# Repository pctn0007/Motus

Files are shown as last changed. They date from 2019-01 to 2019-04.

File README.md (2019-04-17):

<p align="center">
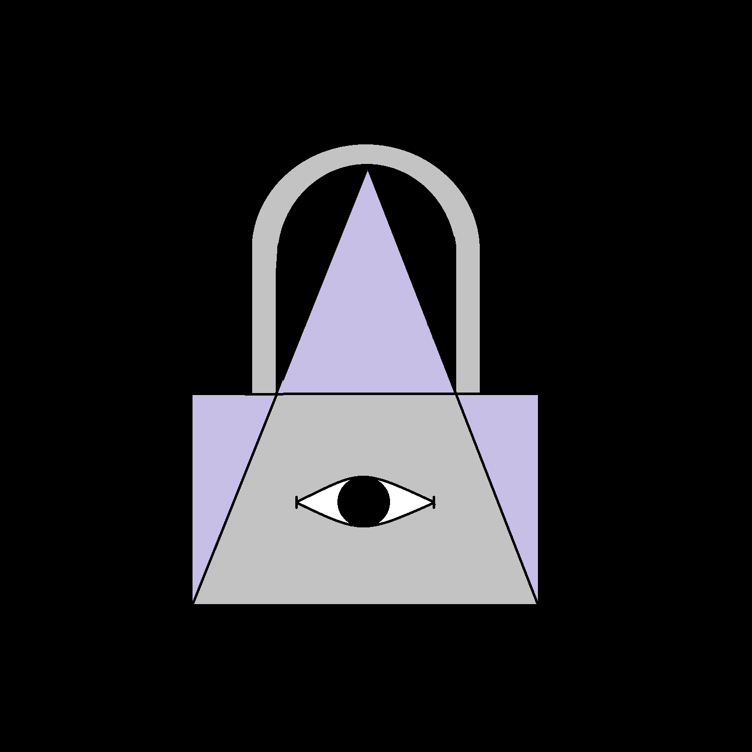
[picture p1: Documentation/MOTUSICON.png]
ICON
  
  <br>
  <b font size="20">M O T U S</b><br>
  <b font size="30">"The Portable Security System"</b>
</p>
<br>
Motus is a Student Project that is designed to be an Active Remote Security System that can be placed within a car, a boat, in your purse, even your purse inside your prius! Or etc. This device is designed to alert the owner of their certain vehicle or valuable items / objects of any individual altering its movement, position or if someone is inside it or manipulating it in general. Motus monitors multiple factors, such as movement, and motion. Motus will snap a picture and alert you of any intrudors or thieves messing with your protected belonging.
<br><br>This project is being worked on by the following people:
<br>- Anthony Pacitto (pctn0007 [MASTER])
<br>- Dariusz Kulpinski (BlueDaroosh)
<br>- Winston Vuong (LosesonWinson)
<br>- All three students are Computer Engineering Students currently studying at Humber College in Toronto, CAN.

<br> [Click here to access the Build Instructions](https://github.com/pctn0007/Motus/blob/master/BUILDINSTRUCTIONS.md)

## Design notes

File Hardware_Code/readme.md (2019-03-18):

# MOTUS Logic:
[MOTUSLOGIC.py](https://github.com/pctn0007/Motus/blob/master/Hardware_Code/MOTUSLOGIC.py)
# Camera / Image Shell Scripts:
[CAMERA.sh](https://github.com/pctn0007/Motus/blob/master/Hardware_Code/CAMERA.sh)
[IMAGE.sh](https://github.com/pctn0007/Motus/blob/master/Hardware_Code/IMAGE.sh)

test_scripts directory contains old testing / reference code.

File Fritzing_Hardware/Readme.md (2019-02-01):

I will stick images of the PCB, Wiring Diagram and Breadboard Eventually in here.

~ Dariusz

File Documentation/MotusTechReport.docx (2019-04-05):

## Motus Technical Report

Prepared by Anthony Pacitto,

Dariusz Kulpinski,

Winson Vuong

Date: 3/22/2019

# Abstract

The Motus Security System(MSS) is a portable security system that would detect motion in front of the device or movement of the device, and after detecting said motion it would capture an image using the Raspberry Pi Camera apparatus attached directly on the device. The MSS after capturing the image would then send the image to a database, and would then be seen on an Android application. This Technical document for the MSS is used to record our progress, and our findings from our progression throughout the project. The document would record what we as a group did to create the hardware for the MSS. Also, we would describe how exactly managed to create our software for both the Raspberry Pi and also our Android application. Problems we faced will also be included and how we as a group managed to move passed them as a group. The report will also contain our weekly updates to our project that would give insight to how the project was managed as a group, and how we worked together to create this project. The final findings of the project will also be included in this document, and will be recorded as detailed as possible for the sake of proper reporting.

# Declaration of Joint Authorship

We, Anthony Pacitto, Dariusz Kulpinski, and Winson Vuong, confirm that this work submitted is the joint work of our group, and no plagiarism has occurred . Any references used in the report will be noted and documented throughout the report. The list of the references used for the report will be included inside the document. For the project Anthony handled the database portion of the project and the app. Dariusz worked on all the physical and hardware portion of the project. And Winson worked on supporting the both of them as an assistant for the project and is working on the app.

# Approved Proposal

# Concluding remarks

# Illustration List

# 1 Introduction

Motus Security System (MSS) is branded as a portable motion sensor that can be used to detect both physical motion and local vibrations (i.e. tampering or movement of the device) in a 100 degree targeted zone. As mentioned, the software being specified within this document is known as: Motus Mobile and its purpose are to provide the MSS user full control and monitoring of basic input data via the MSS hardware device. The Motus Mobile will also contain a login system for multiple users to use the MSS. The software application provides access to the devices remote database system (i.e. Firebase) which evidently stores all sensor data for interpretation, and also the images captured by the Raspberry Pi Camera. The benefit and overall goal of the application will allow for a user to remotely control their device from any location around the globe in order to ensure greater security, all within an efficient manner. It will monitor information such as, device tampering and movement notifications, surrounding motion detection and image capturing based on where a movement was detected. Additional application settings and preferences will be available which can be modified based on the user’s discretion.

# 2 Project Description

2.1 Problem

# 2.2 Rationale Behind Project

# 2.3 Project Scope

# 2.4 Software Requirement Specifications

# 2.4.1 Database

# 2.4.2 Mobile Application

# 2.4.3 Web Interface

# 2.4.4 Networked Platform Communication Software

# 2.4.5 Microcontroller Firmware

# 2.5 Project Overview

# 2.5.1 Bill of Materials

# 2.5.2 Time Commitment

# 2.5.3 Mechanical Assembly

# 2.5.4 PCB and Soldering

# 2.5.5 Power Up

# 2.5.6 Unit Testing

# 2.5.7 Production Testing

# 2.6 Problems Encountered

# 2.7 Approaches

# 2.8 Walkthrough of System

# 2.8.1 Microcontroller

# 2.8.2 Microprocessor

# 2.8.3 Server

# 2.8.4 Phone Application

# 3. Progress Reports

# 3.1 Report 1

# 3.2 Report 2

# 3.3 Report 3

# 3.4 Report 4

# 3.5 Report 5

# 3.6 Report 6

# 4. Conclusions

# 5. Recommendations

# 6. Technical References

# 7. Appendicies

# 7.1 Microcontroller Firmware

# 7.2 Microprocessor Communication Script

# 7.3 Microprocessor Database Communication Program

# 7.4 Database Input Script

# 7.5 Database Retrieval Script for Phone Application

# 7.6 Android Code

# 7.7 Android Phone Application

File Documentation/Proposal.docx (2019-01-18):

Proposal

Team

This letter is to propose the build and production of a portable in-home motion sensor to serve as the backbone for both residential and commercial security systems. The name of the project is known as: Motus (i.e. latin translation of “movement”) and its team consists of the following members: Anthony Pacitto, Dariusz Kulpinski, and Winson Voung.

Introduction

As stated above, Motus will be branded as a portable motion sensor that can be used to detect both physical motion and local vibrations (i.e. tampering or movement of the device) in a targeted zone. In addition, the hardware will support a fully featured mobile application that will provide full control over the device’s settings and detectable readings. With respect to the overall size of the product, the device will contain dimensions that will be small enough for a user to easily mount to any given door, wall, and/or window ledge that they see fit. Currently, there are small in-home sensors; however, not all are portable from one environment to another while maintain mobile compatibility – making Motus somewhat unique versus other makes and models.

Courses and Topics

After much thought, it is important to note that the listed courses and topics that will be relatable to this project are as follows:

- CENG150 - Electronic Circuits:
  - Interpretation of sensor datasheets and electrical circuit design
- CENG153 - Programming in C:
  - Fundamentals of standard input/output and device coding
- CENG252 - Embedded Systems:
  - Implementation of Raspberry Pi with other motion sensors
- CENG322 – Software Project:
  - Java programming for android platform with working database source.

As a team, we plan to use a three-way communication processes between: i) the mobile application; ii) remote cloud/database (i.e. Firebase); and, iii) hardware device. The mobile device will be responsible as rendering the detected any data output via the hardware, in addition to providing a system control interface for the user. The remote cloud will be used to store motion and user data based on the devices input (i.e. HC-SR501 PIR - infrared motion sensor; ADXL 345 – accelerometer; Raspberry Pi 3). It is important to note that this will be the primary way we retrieve digital data and information.

Application and Scheduling

We predict that over the course of the next 13 weeks, we will breakdown the project into 3 phases: 1) design (i.e. mobile application GUI; device designs and layouts), 2) build and develop (i.e. programming of the application, hardware construction/ soldering), and 3) implementation and Testing/Debugging (i.e. testing application on various platforms; testing synchronization between database, app and device; test device in various motion-based environments). Each phase will be completed over an estimated 3.25 weeks accordingly and the workload per team member will be distributed evenly between both hardware and software portions; however, many tasks will be appointed based on comfort level and experience (e.g. greater focus on hardware vs. software).

As for the application, we plan to incorporate, but will not limit to the following activities (screens):

- Splash screen
- Log in and registration
- Motion detection records
- Settings
- Placeholder menus
- Help

The application will contain a hierarchical level system for its activities in order to assure a smooth navigational experience throughout the application. As stated before, we intend to complete this bug-free application over a 13 week period on time. If we do run into any time restraints or complications within the middle, we will negotiate tasks and workload and call for group meetings in order to get back on track; thus, altering our critical path accordingly.

Conclusion

In conclusion, our team feels confident that we can provide a new portable security system that will make it easier for people to portably move there security zone. Not only do we intend to have a working hardware device, but also a fully incorporated Firebase system which communicate over android application platform.

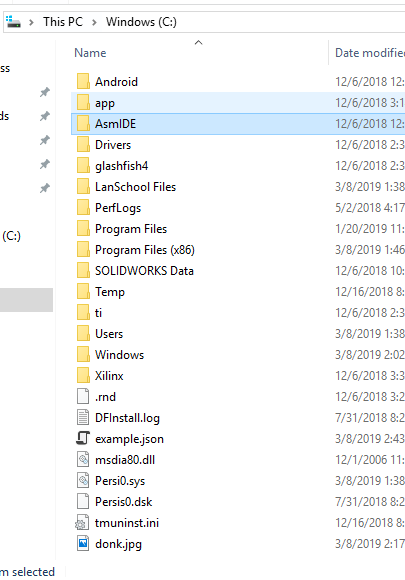
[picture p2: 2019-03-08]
Research/Capture.PNG

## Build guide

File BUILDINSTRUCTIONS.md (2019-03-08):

# MOTUS - The Handheld Security System
## Anthony Pacitto, Dariusz Kulpinski, Winston Vuong 
## CENG 355-0NC
![DeviceImage]()

# BUILD INSTRUCTIONS / How to make a MOTUS device yourself

These are the build instructions on how to make the device. Some items may be more complex to complete, as they need special equipement to complete (ex. PCB builders, CO2 Laser Cutter / Etcher, etc.)

To start off, we should determine what this should look like in the end. More suitably for this project, what should our output look like? Well, fist of all it must detect any security breaches. Such that it can detect if theres motion, or movement of the device itself. In terms of build time for this project, it's a good idea to prepare everything before hand, such as part ordering and source downloads of items and code, pre-manufacturing items and whatsoever. If you are ready to commence the build, you can find a good 3-4 weeks to assemble the entire thing together, as there are many components to review.

## What do we need to start off with?

Several components are required in order to make this project work. All required components for this project is listed below:

- Safety Glasses (Eye protection and other protection you prefer)
- Raspberry Pi 3 B+ Model (Must be I2C ready.)
- SD Card with Raspbian OS (Available Online or install image on own SD card.)
- ADXL345 3 Axis Accelerometer (This is the movement detector. Must be I2C ready.)
- HC-SR501 PIR Sensor Module (This is the motion detector. Must work with GPIo.)
- Standard LED (Used as an indicator for the device)
- 330 Ohm Resistor (To limit voltage on the LED)
- Rapsberry Pi External Camera (For the Photo Component of the device.)
- Breadboarding Platform (Any Size Works)
- USB mouse, USB Keyboard, HDMI cable and HDMI monitor to use the Pi With OR ethernet cable to use the remote desktop function.
- GPIo Cables (male to female connections between board and sensor)
- GPIo Pin Stacking Header (Something that allows you to connect a PCB itself to the Pi)
- 3 Pin Stacking Headers (Used to space the motion sensor from the board)
- Jumper Wires (Used for the PCB component or the breadboarding if preffered)
- Wire stripping / Cutting tools
- Soldering Equipment (Soldering Iron, Lead Free Solder, Proper Ventilation, Wet Sponge, Solder Sucker, etc)
- Printed Circuit Board (PCB. This will be discussed later.)
- PCB design software (Example. Fritzing. This will be discussed later.)
- Device Enclosure (Such as PVC boards. This will be discussed later.)
- Enclosure Design Software (Example, CorelDraw. This will be discussed later.)
- Some means of way to produce the PCB and the enclosure (This will be discussed later.)
- And of course, some money.

The estimated cost of building this device is around $245.95 CAD.

## Phase 1: Testing The Design.

To start off, we need to make sure that we know how to connect our device and how its going to work in the end.

Four connections are required to connect our accelerometer to the raspberry pi. First we need to supply 3.3V, connect the ground, and connect our I2C data bus and clock bus to the approprate SDA and SCL pins on the pi.
Three connections are required to connect the motion sensor to the pi. We need a 5V connection, a ground connection, and a connection to a GPIO pin. For this project, the GPIo pin we will connnect it to is GPIo7.
Two connections are required to connect the LED. A connection to the 5V pin, and to the ground. The Resistor can be connected inline with the LED anywhere.
To connect the camera, simply slide the ribbon cable into the appropriate cable slot on the pi's board.
Below is the breadboard. This is how it is supposed to be connected in the end:
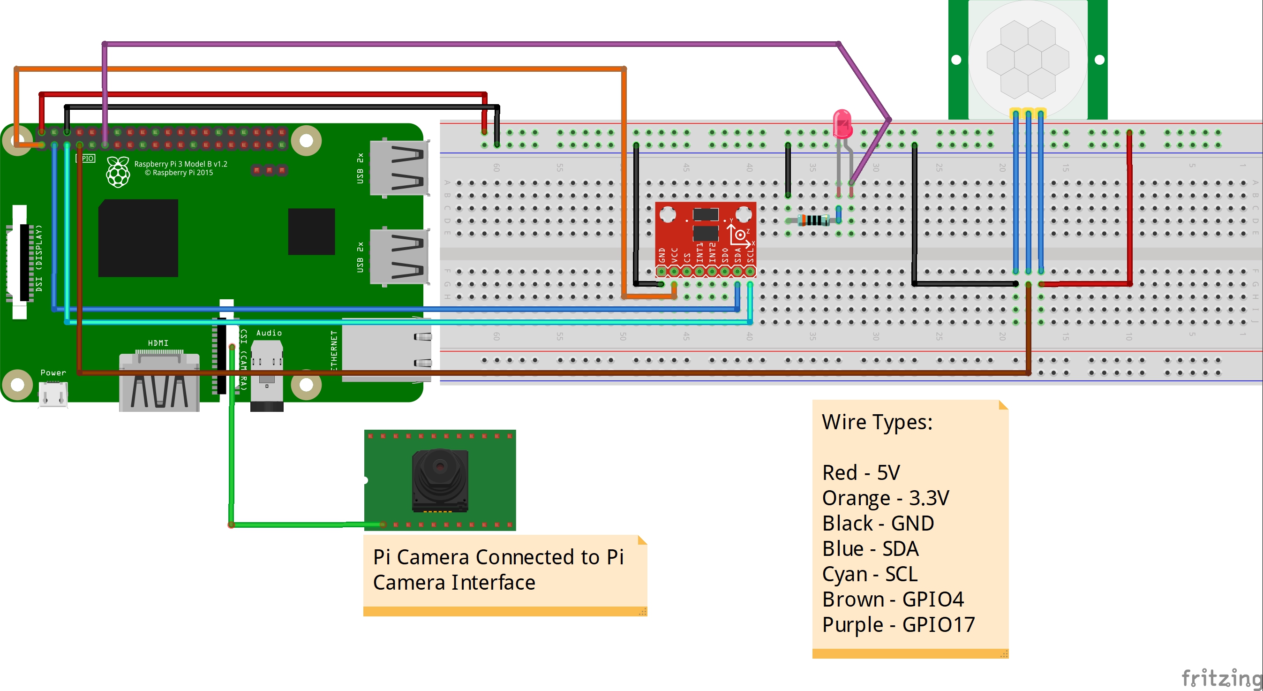
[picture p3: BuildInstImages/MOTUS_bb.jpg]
Breadboard image

#### Pin locations may vary depending on the manufacturer of the sensor itself.
Basically in the end, your wiring must match the schematic as follows:
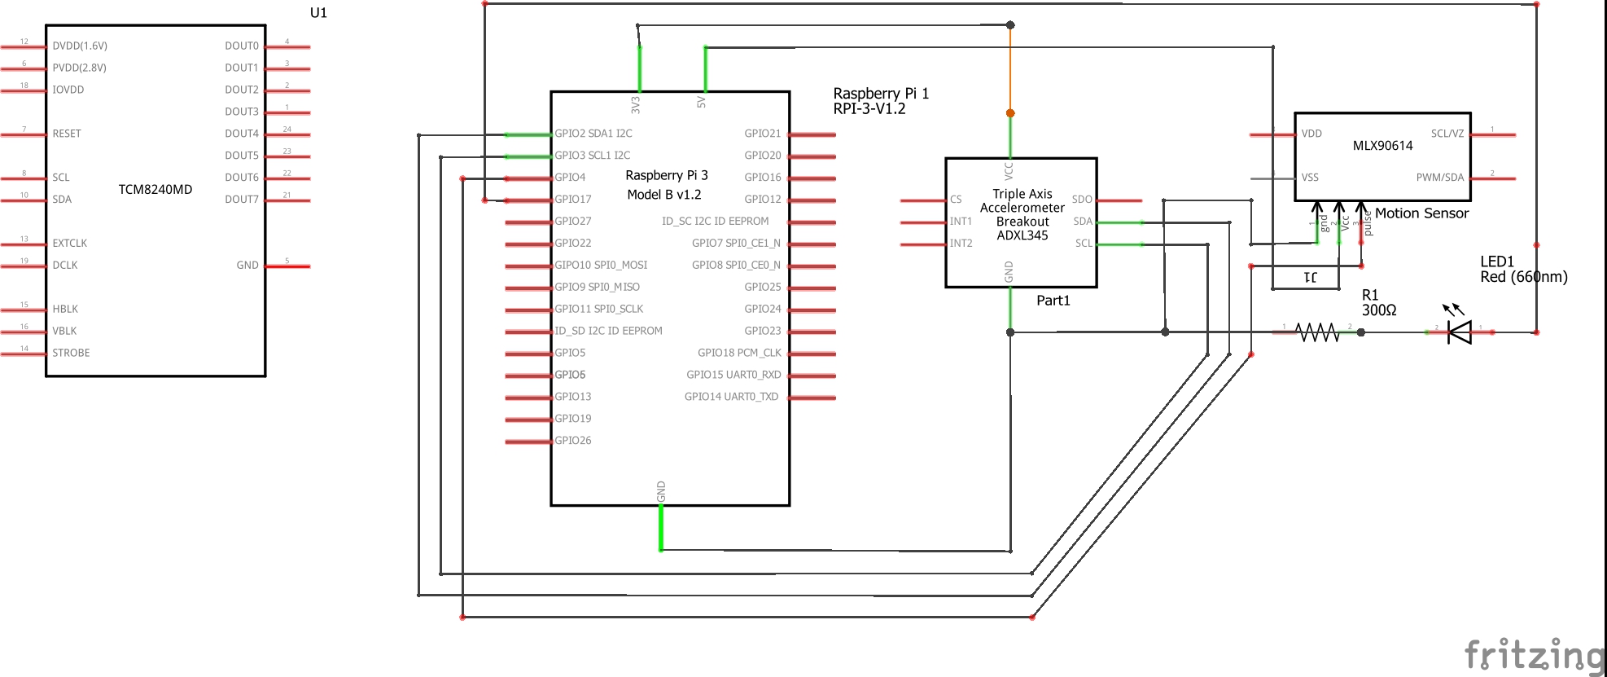
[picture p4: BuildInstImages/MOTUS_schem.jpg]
Wiring Schematic

Once this breadboarding is complete, You have the option to jump towards the Third Phase of the build, which powers on the system, or continue on to the Second Phase to design the circuit board for actual system itself.

## Phase 2: Building a Circuit Board

With our breadboard schematic done, we can now design a circuit board that will eliminate all our wiring in the device. A highly reccomended software for this part is Fritzing. Fritzing is a software that allows you to design a breadboard, wiring diagram, and the circuit board itself with ease.
<br />[Click here to visit Fritzing.org](http://fritzing.org/home/)
<br />Once fritzing is installed, build a breadboard design very similar to the design above. Once designed, a schematic of your board and a PCB template will automatically be generated. All you have to do is simply complete the connections.
<br />For the PCB, make sure that each of the connections are designed to fit the devices, and ensure that they can be soldered on depending on which side the contacts are.
<br />Below is a sample of how the PCB should look like in the end:
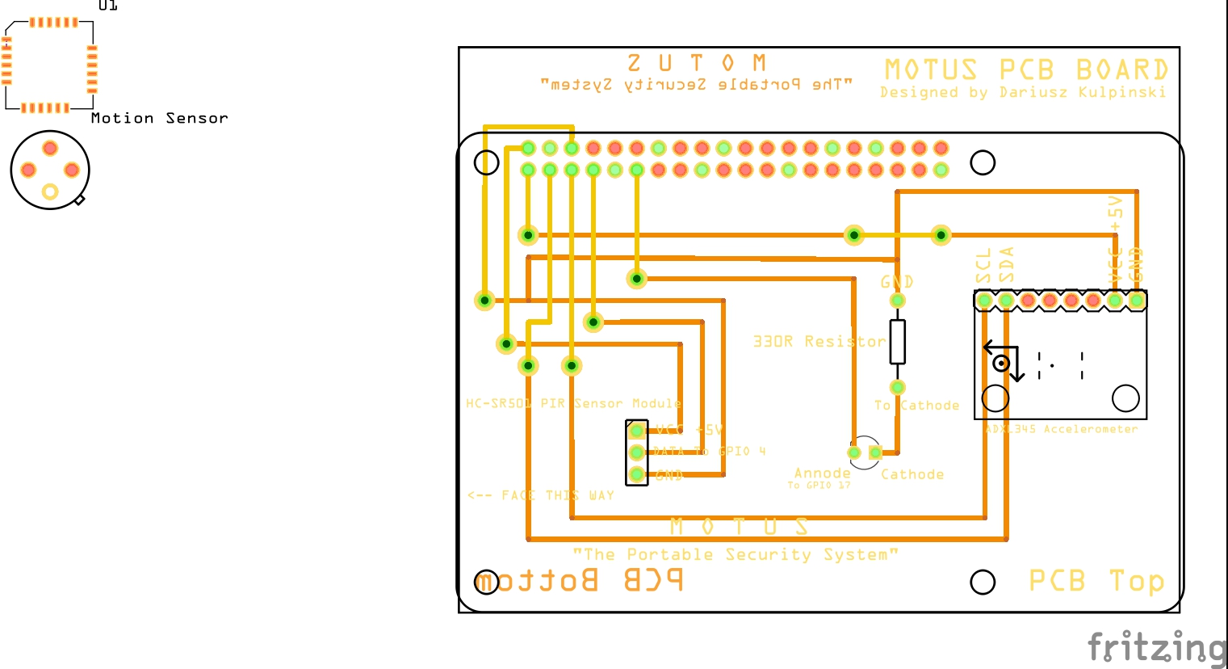
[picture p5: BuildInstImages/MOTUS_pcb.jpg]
PCB Design

<br />[Click here to learn more on how to design a PCB in Fritzing](http://fritzing.org/learning/tutorials/designing-pcb/)
<br />Ensure that the connection to the Pi Header can be soldered on the TOP of the board, and make sure that soldering on the sensor can be done on the BOTTOM of the board. Remember, Yellow lines indicate the TOP, while orange lines indicate the BOTTOM. To connect the bottom and the top together, use VIA'S to link them together. You also have access to the original fritzing file if you want to modify that for yourself. [You can click here to download the fritzing file.](https://github.com/pctn0007/Motus/blob/master/Fritzing_Hardware/MOTUS.fzz)
<br />If you are satisfied with the board design, export the PCB as an Extended Gerber File for manufacturing. If you have access to a PCB builder, you can use that. Otherwise, you need to send these Gerber files to a service that Prints out circuit boards, which may add to your budget.

Once you obtain your circuit board, you can proceed to soldering on the pins. Please ensure that you have proper ventilation for this part, and safety glasses are absolutely mandatory for this part.
[If you need help on soldering, a tutorial can be found here.](https://www.build-electronic-circuits.com/how-to-solder/)
<br />To solder the board, ensure that the sensors pins are soldered on the BOTTOM of the board. Ensure that the PI connectors are soldered on the TOP of the board. To Solder the Vias, take some jumper wire, strip it of its protection and stick it throuhg the via. Solder the jumper on both ends, and cut off the excess. That solders on the via and you linked top to bottom.
<br /> This is an example of how the soldering should be completed:
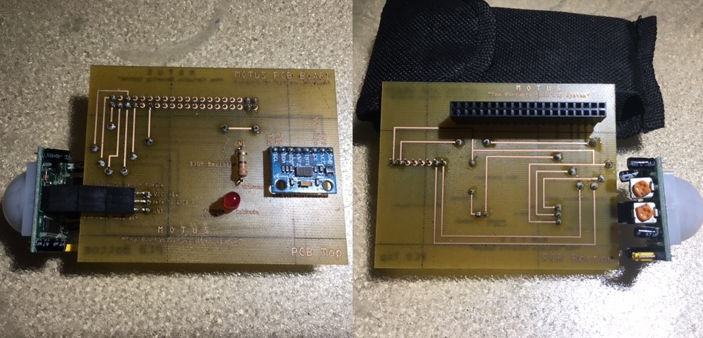
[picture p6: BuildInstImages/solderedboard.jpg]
Soldering Example

Once the board is fully soldered, it's time to move to Phase 3.

## Phase 3: Powering the Accelerometer

In this phase, we will test our design to see if it outputs values and reads from the sensors. This part will be majorly focused on the use of the PI, so this is where the monitor, mouse keyboard and HDMI cable Or Remote Desktop Connection come into play.
If you want to learn more about remote desktop connection and the pi, [you can click here.](http://www.circuitbasics.com/access-raspberry-pi-desktop-remote-connection/)
When you start up your Pi, make sure you complete setup if that has not happened already. The most important part to begin with is to ensure that we can read from our sensor's i2c address. First the Pi must be configured to activate I2C. To do this, go into your Raspberyy Pi Preferences:
Pi Preferences

Under your IO, ensure that the I2C interface is switched to on. That completes this step.
The next step is the i2c tools. To install this, open the terminal and type in:
#### sudo apt-get install -y i2c-tools
<br /> Input your credentials and allow the installation to complete. Once that's done, we check if our sensors i2c address is found on the GPIo. Run the following command in the terminal:
#### sudo i2cdetect -y 1
<br /> Running this, you should get the following result:
GPIo I2C pickup
<br />If you see the address of 0x53, you are all set and the accelerometer is ready. Otherwise you need to go back and see what mistakes you have done.

Let's understand how the code is supposed to work in the end. First of all, when working with I2C, we need to program the system to ensure that it will register and read I2C devices that are connected to the I2C bus. Next thing is how this data should be processed. It depends on how you want to display and store the information. Let's say for example we want to take data from a sensor, store it in a database, and have a mobile device read from that database to display the current values for the accelerometer. Below is some PSEUDO CODE that would demonstrate what we would like to do:
`<https://github.com/BlueDaroosh/handheldSpedometer/blob/master/PseudoCodeAssignment/WriteFromServer.txt>`
`<https://github.com/BlueDaroosh/handheldSpedometer/blob/master/PseudoCodeAssignment/ReadToClient.txt>`

The next part is programming the device itself to take inputs from the sensors. This is written under python, but should be simple to implement. Run Thonny on the pi. Once thonny runs, save a .py file anywhere. Below is a link to the source code.
<br />[Click here to access the source code.](https://github.com/pctn0007/Motus/blob/master/Hardware_Code/MOTUSLOGIC.py)
<br />Also, there is a shell script that is required in order to operate the camera function of the script. The shell script is a call to the raspistill command, and [can be accessed here.](https://github.com/pctn0007/Motus/blob/master/Hardware_Code/MOTUSCAMERA.sh)
<br />Please ensure that the database credentials are modified in the python script so that it connects to the database you configure in Phase 4 of the instructions.
<br />Once you format everything properly, and make sure the syntax is correct, you can run the script. By running the script, the device will search for motion or check for movement. If either are true, the device will emit a warning signal light, and activate the camera. The photo should be accessible under the home directory.
<br /> Feel free to look at the script, and modify it however you please.

## Phase 4: The Database and App
The recommended database to use for this build is known as Google's Firebase realtime database and storage system. First, you must create a google account in order to register your application (via Android Studio) to your remote database. Next, we need to create a new project in Firebase by clicking Add Project under your Firebase Console. It is important to follow each setup step accordingly by importing the correct libraries into your application and project gradle files. It is also important to make sure you add the google-support.json file into your Android Studio application folder/directory. Once you have successfuly added your Android application to your database for connection, we must create a link between the application and the database for development. The video link below will provide a step-by-step tutorial on how to go about creating, adding and connecting your new Android project to your database:

https://www.youtube.com/watch?v=YVu_xSzn2u0

It is important to note that once all setup is complete, you must alter your user permissions accordingly in order to enable read and write privledges so that individuals working on the application have the ability to read/write data to the database.

## Phase 5: The Enclosure

To do the enclosure is totally up to you, but it is highly reccomended so that your components are secured and protected. The example case for this project was made using CorelDraw. Other design softwares can be used as well to create the enclosure.
[This is a link to the example closure, which can be modified to your circuit design.]()
NOTE: This is a coreldraw file, therefore you require coreldraw to edit this file. Unless you do not have a free trial, this may be an additional $600 CAD to the budget. Ridiculous price.
<br />Once you design your enclosure for the circuit, you can take the file and use a locally available CO2 laser etcher or other tool that corresponds to your design. Otherwise you may also require to use a service which will build the enclosure for you, but at an added cost for the budget. Once you get your enclosure parts, build the entire thing together, and that is your final result. Below are images of an example of the final result:
![Enclosure Top]()
![Enclosure Back]()
This marks the end of the project. This entire system is now yours to modify and cherish.

## Final Comments
Motus is a bit of a rough idea, however the entire system can be beneficial to the whole valuable protection scheme. Below are references on how the MOTUS platform was designed and built. MOTUS is under a GNU General Public License, so that it is available for you to use, change, modify or redistribute your modification.

#### Credits and Works Cited. Without these, the project would have not been possible:
Dcube Tech Ventures. (N.D.) 3-AXIS ACCELEROMETER, ADXL345 WITH RASPBERRY PI USING PYTHON. 
Obtained From: https://www.instructables.com/id/3-Axis-Accelerometer-ADXL345-With-Raspberry-Pi-Usi/
<br />AviV1. (N.D.) HOW TO USE THE ADXL345 ON RASPBERRY PI.
Obtained From: https://www.instructables.com/id/how-to-use-the-ADXL345-on-Raspberry-pi/
<br />GPIo: https://www.raspberrypi.org/documentation/usage/gpio/
<br />I2C Wiring: https://www.anstack.com/blog/2016/07/05/accelerometer-intro.html
<br /> Humber College - CENG 317 Hardware Production Tech Course
<br /> Humber College - CENG 355 Capstone Project Course
<br /> Humber School of Applied Technology - Computer Engineering Technology

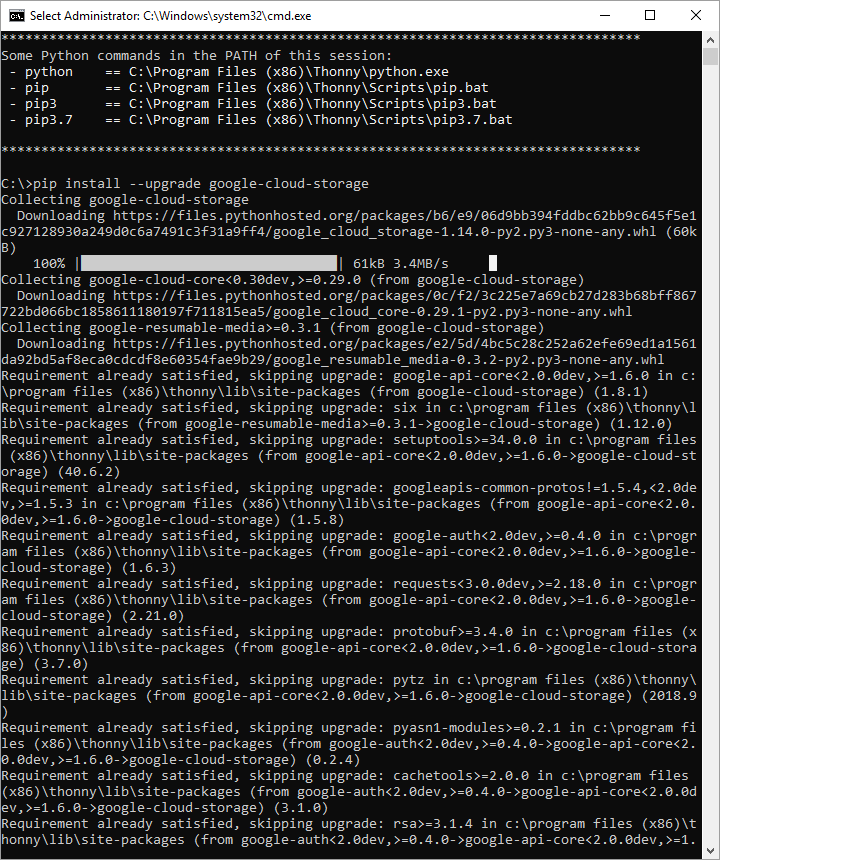
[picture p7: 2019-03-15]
Research/install_google-cloud-storage.png

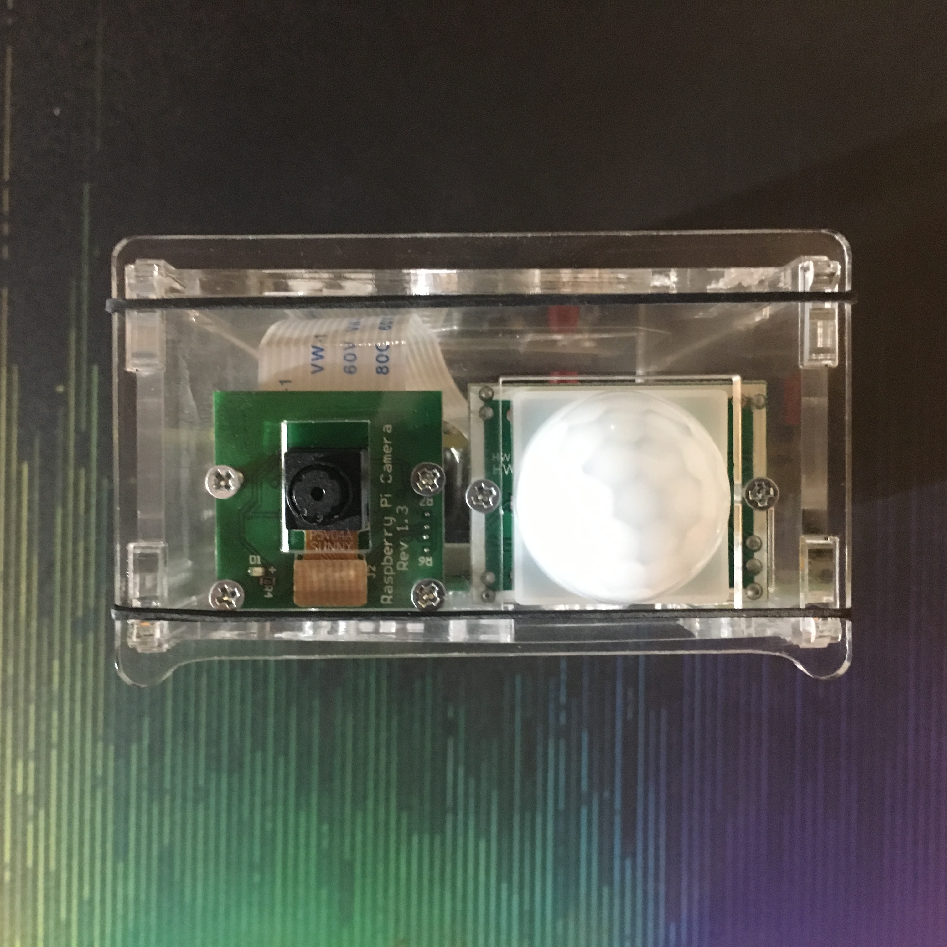
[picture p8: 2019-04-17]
BuildInstImages/MOTUSFront.JPG

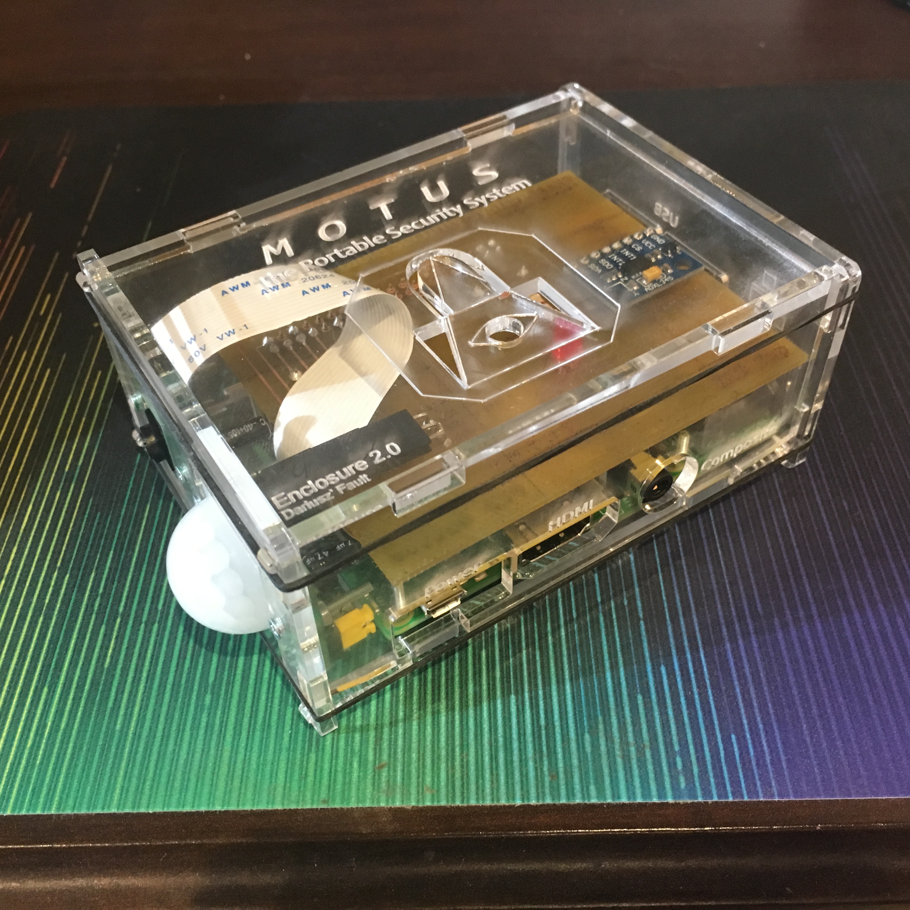
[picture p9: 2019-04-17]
BuildInstImages/MOTUSOver.JPG

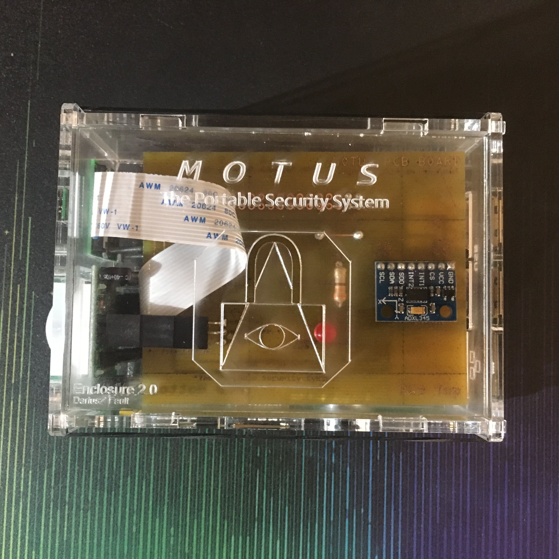
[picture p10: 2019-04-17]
BuildInstImages/MOTUSTop.JPG

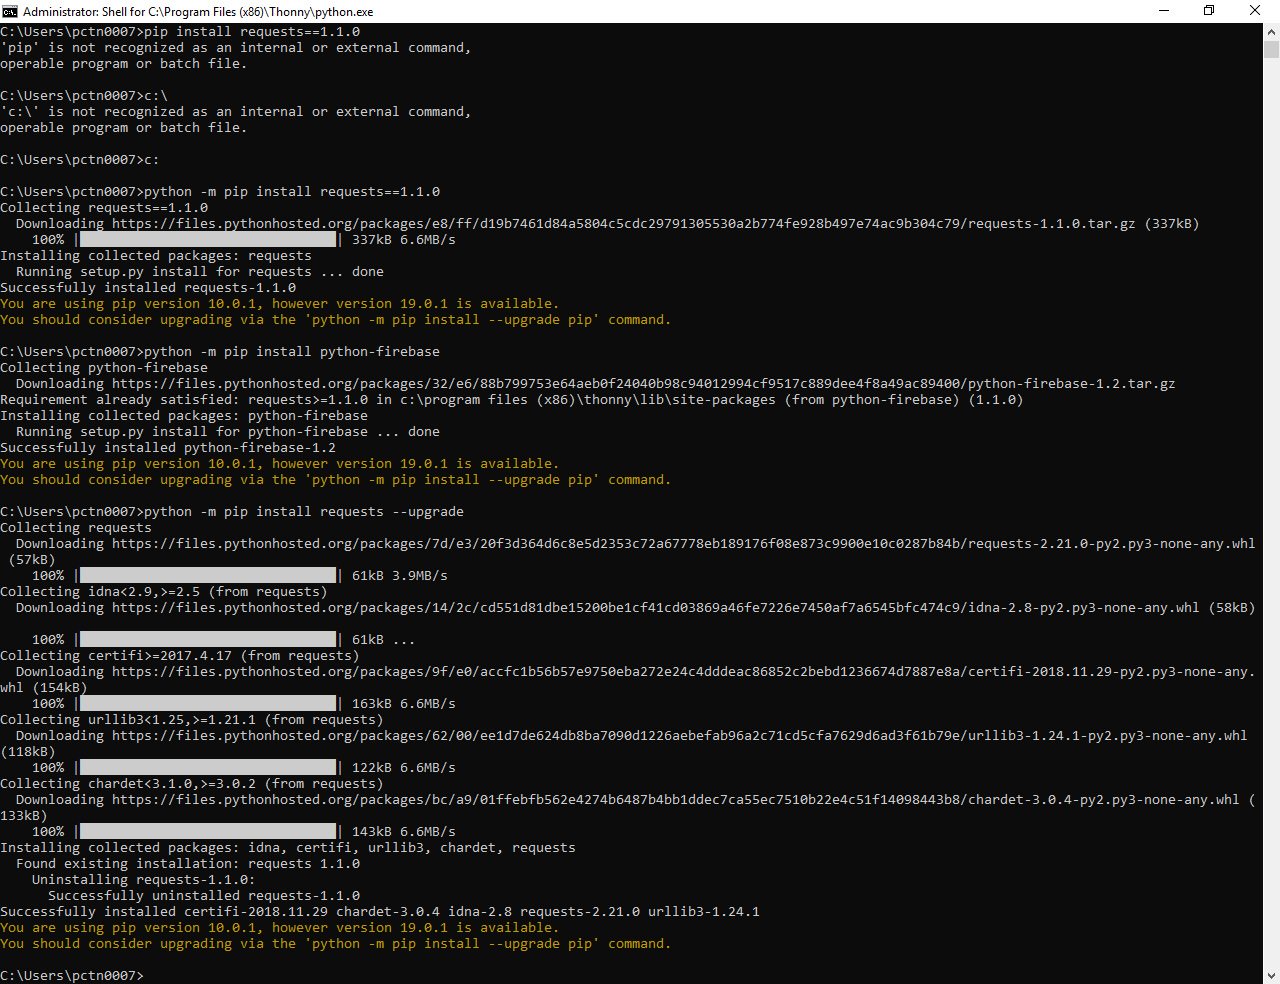
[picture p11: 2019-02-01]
Research/install-python-commands.png

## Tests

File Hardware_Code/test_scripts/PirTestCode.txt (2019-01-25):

https://www.raspberrypi.org/forums/viewtopic.php?t=49451
https://www.raspberrypi.org/forums/viewtopic.php?t=38753

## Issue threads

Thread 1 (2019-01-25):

Camera Speed

LosesonWinson, 2019-01-25:
It takes 5 seconds for the camera to take a image may need to lower the time.

BlueDaroosh, 2019-02-04:
the shell command is as followed:

raspistill -t [time in milliseconds] filename.jpg

Winston, you found the solution... so why didn't you close this issue???

pctn0007, 2019-04-12:
well well, should of closed the issue. Hmhmm

Closed 2019-02-04.

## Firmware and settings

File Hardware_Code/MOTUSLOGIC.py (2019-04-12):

# MOTUS "The Portable Security System"
# LOGIC FILE / SENSOR PERFORMANCE

# MOTION SENSOR - Will be active under GPIO 4
# LED - Will be active under GPIO 17
# ACCELEROMETER - Will be active under I2C 0x53
# FIREBASE - Will be active under database: ExampleProg

# MOTUSLOGIC.py Program by Dariusz Kulpinski
# Database Functions and Comms. by Anthony Pacitto
# Shell file to run camera function: CAMERA.sh
# Shell file to run image handling: IMAGE.sh

# UPDATED: 2019-04-11

# DECLARATIONS AND INITIALIZATION ------------------------------------------

import smbus
import time
import os
import datetime
import signal
import sys
import random
import json
import RPi.GPIO as GPIO
from google.cloud import storage
from firebase import firebase
from time import gmtime, strftime

# MACROS -------------------------------------------------------------------

sensitivity = 10 # The Accelerometers Sensetivity for Detection
                 # 0 = MAX Sensitivity | Any positive value = less sensitive

refreshrate = 1.0 # TIME BETWEEN CHECKS FOR SECURITY BREACHES

sleeptime = 10.0 # Suspend Time after Security Trigger
                 # SECONDS.MILLISECONDS

dcheck = 0       #Prevention of Double Movement Detection 
				 
boxid = '1'      # unique Box ID
				
pic = '/home/pi/SECURITYIMAGE.jpg' # snapshot file name
			# TO BE UPLOADED TO DATABASE
							
imagetosend = 'null' # initial image name
	             # RANDOMLY GENERATED THROUGH CODE
			
# Motion types (i.e. case motion vs. stimuli motion).
MOTION_TYPE_I2C = '0' #case
MOTION_TYPE_GPIO = '1' #stimuli

#INTERRUPT Catcher
def signal_handler(sig, frame):
    GPIO.output(17,GPIO.LOW)
    sys.exit(0);
signal.signal(signal.SIGINT, signal_handler)

# Get I2C bus
bus = smbus.SMBus(1)

# Get Firebase Connection
firebase = firebase.FirebaseApplication('https://exampleprog-69f69.firebaseio.com/', None)
credential_path = "/home/pi/Exampleprog.json"
os.environ['GOOGLE_APPLICATION_CREDENTIALS'] = credential_path
client = storage.Client()
bucket = client.get_bucket('exampleprog-69f69.appspot.com')

# Get GPIO devices
GPIO.setmode(GPIO.BCM)
GPIO.setwarnings(False)
GPIO.setup(17,GPIO.OUT) # LED LIGHT ADDRESS
GPIO.setup(4,GPIO.IN)   # MOTION SENSOR ADDRESS
GPIO.output(17,GPIO.HIGH) #Default LED STATUS set to HI for power status

# PRIMARY LOGIC LOOP (NO MORE INITIALIZATION) ------------------------------------------

xAcclafter = 0   # Motion Defaults Set
yAcclafter = 0   # For X , Y, Z
zAcclafter = 0   # Axis'

print("MOTUS is ready to defend. Waiting for event...")
while True:

# ADXL345 MOTION OBSERVATION LOGIC

    bus.write_byte_data(0x53, 0x2C, 0x0A)
    bus.write_byte_data(0x53, 0x2D, 0x08)
    bus.write_byte_data(0x53, 0x31, 0x08)

    time.sleep(0.5) #Refresh Rate

    data0 = bus.read_byte_data(0x53, 0x32)
    data1 = bus.read_byte_data(0x53, 0x33)

    xAcclbefore = ((data1 & 0x03) * 256) + data0
    if xAcclbefore > 511 :
            xAcclbefore -= 1024

    data0 = bus.read_byte_data(0x53, 0x34)
    data1 = bus.read_byte_data(0x53, 0x35)

    yAcclbefore = ((data1 & 0x03) * 256) + data0
    if yAcclbefore > 511 :
            yAcclbefore -= 1024

    data0 = bus.read_byte_data(0x53, 0x36)
    data1 = bus.read_byte_data(0x53, 0x37)

    zAcclbefore = ((data1 & 0x03) * 256) + data0
    if zAcclbefore > 511 :
            zAcclbefore -= 1024

# IF MOVEMENT HAS BEEN DETECTED ON THE DEVICE ----------------------------------
    
    # Skips the Initialization values on first loop
    if(dcheck is 0 and xAcclafter is not 0 and yAcclafter is not 0 and zAcclafter is not 0):
    
        xChange = xAcclbefore - xAcclafter
        yChange = yAcclbefore - yAcclafter
        zChange = zAcclbefore - zAcclafter
        
        if(xChange >= sensitivity or xChange <= -sensitivity or
           yChange >= sensitivity or yChange <= -sensitivity or
           zChange >= sensitivity or zChange <= -sensitivity):
            
            #CAMERA CALL
            os.system("./CAMERA.sh")
            
            print("MOVEMENT DETECTED ON THE DEVICE")
            dtime = strftime("%d %b %Y %H:%M:%S", gmtime()) # detection timestamp
            imagetosend = (strftime("%d%b%Y_%H_%M_%S.jpg", gmtime()))
            GPIO.output(17,GPIO.LOW)
            time.sleep(0.4)
            GPIO.output(17,GPIO.HIGH)
            time.sleep(0.4)
            GPIO.output(17,GPIO.LOW)				
				
            #DATABASE INSERTION
            data = {'BoxID': boxid,'Picture': imagetosend,'Date': dtime,'SType': MOTION_TYPE_I2C}
            sent = json.dumps(data)
            result = firebase.post('/Detections/', data)
				
	    #IMAGE INSERTION
            zebraBlob = bucket.blob("Detections/" + imagetosend)
            zebraBlob.upload_from_filename(filename=pic)
            
            print("Data Uploaded Succesfully. Alert sent to database.")
                
            # COOLDOWN / IMAGE HANDLING
            os.system("./IMAGE.sh")
            time.sleep(sleeptime) #Trigger Cooldown
            print("COOLDOWN EXPIRE - %d SECONDS" %sleeptime)
            dcheck = 1 # PREVENTION OF REPEAT
    else:
        dcheck = 0 # PREVENTION OF REPEAT
                
    # End Movement Check
                
    # Assign Values for Next Movement Check
    xAcclafter = xAcclbefore
    yAcclafter = yAcclbefore
    zAcclafter = zAcclbefore
    
    # MOTION SENSOR DETECTION ------------------------------------------------------
    
    motion = GPIO.input(4) # HI | LO assignment to motion
        
    if motion is 1: # if motion is HI
        
        #CAMERA CALL
        os.system("./CAMERA.sh")
            
        print("MOTION DETECTED TOWARDS THE DEVICE")
        dtime = strftime("%d %b %Y %H:%M:%S", gmtime()) # detection timestamp
        imagetosend = (strftime("%d%b%Y_%H_%M_%S.jpg", gmtime()))
        GPIO.output(17,GPIO.LOW)
        time.sleep(0.1)
        GPIO.output(17,GPIO.HIGH)
        time.sleep(0.1)
        GPIO.output(17,GPIO.LOW)
        time.sleep(0.1)
        GPIO.output(17,GPIO.HIGH)
        time.sleep(0.1)
        GPIO.output(17,GPIO.LOW)
        time.sleep(0.1)
        GPIO.output(17,GPIO.HIGH)
        time.sleep(0.1)
        GPIO.output(17,GPIO.LOW)
		
        #DATABASE INSERTION
        data = {'BoxID': boxid,'Picture': imagetosend,'Date': dtime,'SType': MOTION_TYPE_GPIO}
						
        sent = json.dumps(data)
        result = firebase.post('/Detections/', data)
	
	#IMAGE INSERTION
        zebraBlob = bucket.blob("Detections/" + imagetosend)
        zebraBlob.upload_from_filename(filename=pic)
				
        print("Data Uploaded Succesfully. Alert sent to database.")
        
        # COOLDOWN / IMAGE HANDLING
        os.system("./IMAGE.sh")
        time.sleep(sleeptime)
        print("COOLDOWN EXPIRE - %d SECONDS" %sleeptime)
        
    # End Motion Check

    time.sleep(refreshrate) # REFRESH RATE OF CHECKS
    GPIO.output(17,GPIO.LOW)
    time.sleep(0.1)
    GPIO.output(17,GPIO.HIGH)
       
# END PROGRAM ==================================================================

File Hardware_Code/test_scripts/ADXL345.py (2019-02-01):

# Distributed with a free-will license.
# Use it any way you want, profit or free, provided it fits in the licenses of its associated works.
# ADXL345
# This code is designed to work with the ADXL345_I2CS I2C Mini Module available from dcubestore.com
# http://dcubestore.com/product/adxl345-3-axis-accelerometer-13-bit-i%C2%B2c-mini-module/

import smbus
import time

# Get I2C bus
bus = smbus.SMBus(1)

# ADXL345 address, 0x53(83)
# Select bandwidth rate register, 0x2C(44)
#		0x0A(10)	Normal mode, Output data rate = 100 Hz

while True:

    bus.write_byte_data(0x53, 0x2C, 0x0A)
# ADXL345 address, 0x53(83)
# Select power control register, 0x2D(45)
#		0x08(08)	Auto Sleep disable
    bus.write_byte_data(0x53, 0x2D, 0x08)
# ADXL345 address, 0x53(83)
# Select data format register, 0x31(49)
#		0x08(08)	Self test disabled, 4-wire interface
#					Full resolution, Range = +/-2g
    bus.write_byte_data(0x53, 0x31, 0x08)

    time.sleep(1.0) #Refresh Rate

# ADXL345 address, 0x53(83)
# Read data back from 0x32(50), 2 bytes
# X-Axis LSB, X-Axis MSB
    data0 = bus.read_byte_data(0x53, 0x32)
    data1 = bus.read_byte_data(0x53, 0x33)

# Convert the data to 10-bits
    xAccl = ((data1 & 0x03) * 256) + data0
    if xAccl > 511 :
            xAccl -= 1024

# ADXL345 address, 0x53(83)
# Read data back from 0x34(52), 2 bytes
# Y-Axis LSB, Y-Axis MSB
    data0 = bus.read_byte_data(0x53, 0x34)
    data1 = bus.read_byte_data(0x53, 0x35)

# Convert the data to 10-bits
    yAccl = ((data1 & 0x03) * 256) + data0
    if yAccl > 511 :
            yAccl -= 1024

# ADXL345 address, 0x53(83)
# Read data back from 0x36(54), 2 bytes
# Z-Axis LSB, Z-Axis MSB
    data0 = bus.read_byte_data(0x53, 0x36)
    data1 = bus.read_byte_data(0x53, 0x37)

# Convert the data to 10-bits
    zAccl = ((data1 & 0x03) * 256) + data0
    if zAccl > 511 :
            zAccl -= 1024

# Output data to screen
    print ("Acceleration in X-Axis : %d" %xAccl)
    print ("Acceleration in Y-Axis : %d" %yAccl)
    print ("Acceleration in Z-Axis : %d" %zAccl)
    print ("---------------------------")

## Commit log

2019-01-18 Create ExamplePirMotionProjectLink
    https://maker.pro/raspberry-pi/tutorial/how-to-interface-a-pir-motion-sensor-with-raspberry-pi-gpio
2019-01-18 Create sample_project_kotlin
2019-02-05 PCB fix / repair Updated Fritzing File
    [MOTUS.fzz]
2019-02-05 Updated / Repaired PCB Gerber Files
2019-02-05 Removal of Flawed PCB Gerber
2019-02-05 Updated / Repaired Gerber Files
    [MOTUS_contour.gm1, MOTUS_copperBottom.gbl, MOTUS_copperTop.gtl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]
2019-02-15 MOTUS Logic Code / Camera Shell Script
    Requires database connectivity to be implemented
2019-04-11 Updated With Fixed Fields and Added Stability
    [MOTUSLOGIC.py]
2019-04-12 Fully Updated and Stabilised for Runtime Service
    [MOTUSLOGIC.py]
2019-04-12 App and Device Icon
